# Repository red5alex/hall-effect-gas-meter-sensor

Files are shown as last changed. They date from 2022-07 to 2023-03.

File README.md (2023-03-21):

# HallEffectGasMeter

**Reading a Gas Meter with Magnetic Encoder using a Hall Effect sensor and an ESP32**

Building a device for reading the pulse count of a gas meter using a hall effect sensor, and sending the counter value to an MQTT broker for further processing. I tried it over one winter and it worked almost perfekt (lost about 1% of the pulses). **It was, however, necessary to solder the wires instead of using the DuPont connectors shown in the pictures below.**

**Note**: Besides using the magnetic counter, the Actaris G4 RF1 also features a reflective encoder on the .001-wheel, allowing for optic reading with 10-fold resolution than the magnetic encoder on the .01 wheel. I realized this only when I already had completed the build, and would have probably gone that way if I would have been aware of it earlier. I recommend to check out Geert Meersman's project https://github.com/geertmeersman/energie-meter which uses this approach.

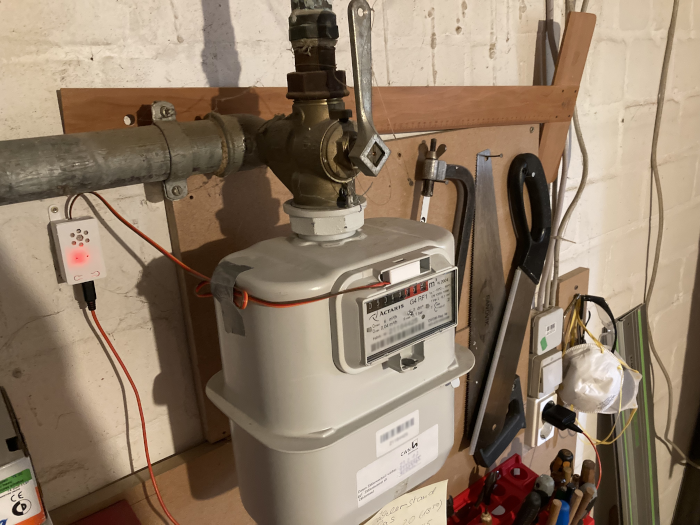
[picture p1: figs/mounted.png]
picture of the sensor mounted to the gasmeter


## Hardware used

- 1 x hall effect sensor 4913B TLE4913 (49E)
- 1 x ESP32 or ESP8266 (or any microcontroller board with WiFi and ADC)
- 3 x Dupont wires (female-female)
- some kind of server to send MQTT messages to (e.g. node-red, home-assistant...)

This hall effect sensor is latching, meaning that it shifts between a HIGH and a LOW state with hysteresis.
The states do depend on the reference voltage of the ESP, so they are different if the board is powered using 3.3V input or 5V (USB).

Note: I tried a classic mechanical Reed sensor with this setup to no avail. Changing to a digital sensor with inbuilt hysteresis made the difference

## Checking the gasmeter

My gasmeter is an Actaris G4 RF1, however I am positive this setup can read-out any other meter with a magnetic pulse.

One of the rollers contains a magnet encoder. I was able to figure out which one it is by moving a strong magnet in the vicinity which caused the relevant one to wiggle a little bit. The sensor must be placed close to this roller.

## 3D printed sensor holder

To hold the sensor in place, I have created a printable piece of plastic that press-fits into the slot above the holder and holds the sensor and cable firmly in place. Find the 3D print files here: https://www.printables.com/model/247665-hall-effekt-gas-meter-reader

The CAD model (made in OnShape) can be found [here]([https://www.google.com](https://cad.onshape.com/documents/e0d259fd877c1182a09bbc17/w/994389497a324f97073d213b/e/8d6a3ead179d19c52f29340c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)

If you do not have a 3D printer, play dough should do just fine :)

After printing, the sensor slides into the little notch. Now, attach the dupont cables to the sensor's terminals and press them into the little grove.
On the picture, I replaced the three original single dupont shells with a triple one, which makes handling a bit easier. If you go with the original terminals, you can secure them by wrapping sticky tape around it.
**Note from future author**: I only got a stable connection when actually soldering the wires, the Dupont connectors created false readings from time to time.

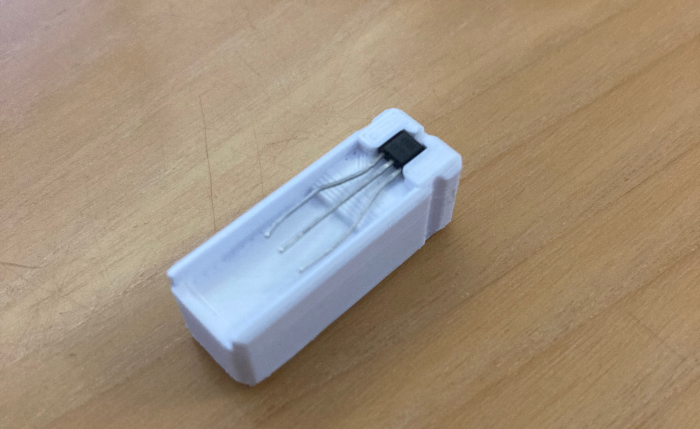
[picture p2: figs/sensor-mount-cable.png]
attach the cables and push in grove


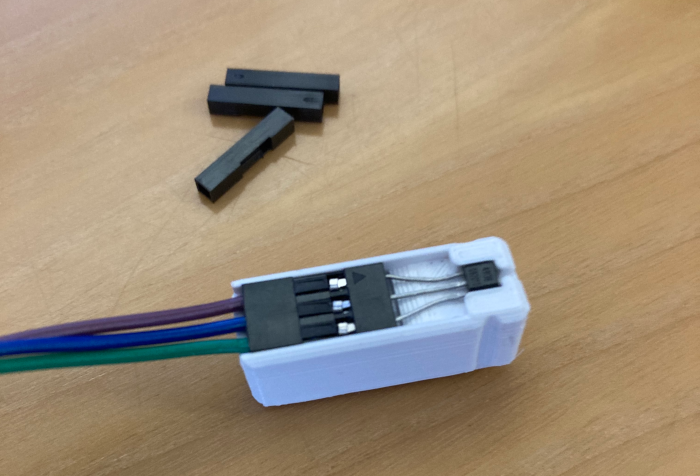
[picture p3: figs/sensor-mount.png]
slide the sensor in the notch


The whole assembly now slides into the slot above the digit rollers of the meter. There is a slit on the side of the mount to indicate the sensors position (highlighted with a pen on the picture), which should be placed directly above the roller containing the magnet.

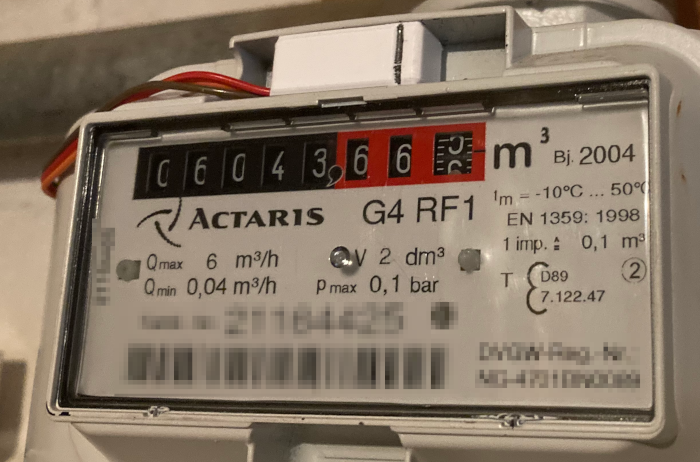
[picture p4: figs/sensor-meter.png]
slide the assembly into the slot above the meter digit rollers


## Wiring

Connect the opposite end of the Dupont cables with the corresponding terminals of the Microcontroller>

- GND to GND
- 3V3 to 3V3
- The signal terminal to GPIO34

You can choose another GPIO with ADC capability (see pinout of you DevBoard). Note: On ESP32, you cannot use the pins connected to ADC2 when using WiFi.

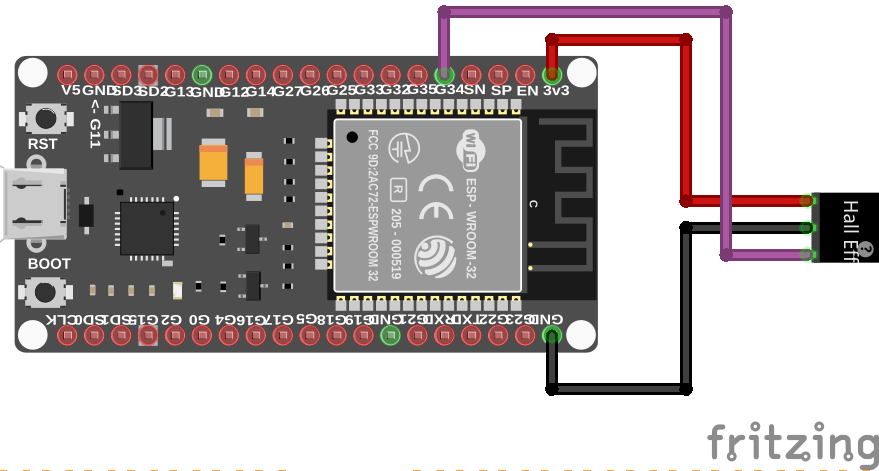
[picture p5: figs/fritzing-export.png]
wiring schematics


## The Ardunio Sketch

The Arduino sketch in the repository contains several configuration files:

- `are_wifi_config.h` sets the hostname and LED port
- `are_mqtt_config.h` configures the MQTT broker, topic etc. If using a public broker (e.g. HiveMQ), make sure to change the default topic.
- `credentials-template.h` must be renamed to `credentials.h`. Add you WiFi name and password here)
- The pinout for the LED and Sensor input can be changed in the `arduino-sketch.ino` directly.

Compile and upload, and check the Serial monitor.
At startup, the LED (if present) will flash until network connectivity is present.

After that, the status LED will be on if the sensor is connected but not detecting the presence of the magnet. Check the connection if it does not come up.

Place a magnet close to the sensor and check if it will turn off. If not, you may need to adjust the threshold voltage in the code (it differs e.g. if powering the ESP32 board via a 5V supply (USB) or a 3.3V supply).

If your board has no in-built or external LED, use the Serial Monitor instead.

## 3D printed case for MicroController

DuPont wires do not attach very reliantly on the ESP32 connectors, so it is advisable to encapsulate the microcontroller to make sure they do not fall off when moving the cables.

I used the [ESP32 Open MQTT gateway box](https://www.thingiverse.com/thing:5345637) by [Simedru Florin](https://https://www.thingiverse.com/simedruflorin) as an enclosure for my ESP32 DevKit (Checkout his designs if using other boards, e.g. ESP8266).

The Dupont cables can be routed through its openings and secured with hotglue. Below a picture of the final assembly:

picture of the sensor mounted to the gasmeter

## Example Application with Node-RED

The repository contains a minimal appliacation example, where the ESP32 sends the current count via an MQTT broker to node-red.

example nodes in node-red GUI

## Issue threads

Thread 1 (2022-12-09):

Update about the project

KevinWillemarck, 2022-12-09:
Hi, just saw this project because I am looking to do the same with my installation. I was just wondering since it is now winter if your setup is working?

jksukino, 2023-02-16:
I'm interested in this project too

geertmeersman, 2023-02-16:
Hi, I tried it but it gave me from time  to time inaccurate readings.
Have changed it and documented it here: https://github.com/geertmeersman/energie-meter

red5alex, 2023-03-21:
Hi All,
Sorry for the late reply. I have finally found the time to test the setup and it worked out that except for a few glitches it works. However I believe @geertmeersman 's approach is superior, as the 0.1 m³ resolution of the magnetic pulse is somewhat low. I have therefore added a recommendation for your approach in the description. When I noticed the reflective surface myself I was already finished with the setup and regretted not going that way already ;). If for any reason I have to rework this setup I may try combining both sensors as it would provide some error check.

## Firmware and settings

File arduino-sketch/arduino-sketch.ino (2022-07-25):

/*
  Sketch for reading a Hall Latch Sensor

  If this does not perform, these are ideas to improve:
  - Add voltage divider to board for larger input range of sensor
  - add hysteresis in this script as additional noise filter
  - only trigger if there was no state change for n seconds.

*/

#include <Arduino.h>
#include <PubSubClient.h>

#include "credentials.h"

// load wifi library and - settings
#include "are_wifi_config.h"
#include "are_wifi.h"
#include "are_mqtt_config.h"
#include "are_mqtt.h"

// pin definition
const int analogInPin = 34;  // Connect to Signal pin of 4913B TLE4913 Hall Effect Sensor
const int LedPin = GPIO_LED;  // Analog input pin that the potentiometer is attached to
const int threshold = 4094;  // this is for 5V Power Supply

// variables
long lastMsg = 0; // time counter for MQTT intervalls
int state = 1;
int counter = 0;
int sensorValue = 0;
int sensorValue_last = 0;
bool sensor_high = false;
bool sensor_rising = false;
bool notify_serial = false;
bool notify_mqtt = false;


//MQTT settings
WiFiClient espClient;
PubSubClient mqttclient(espClient);

/* MQTT callback
   This code sections reacts to incoming MQTT messages.
*/

void callback(char* topic, byte* message, unsigned int length) {
  Serial.print("mqqt message arrived on topic: ");
  Serial.println(topic);

  // cast payload to string object
  String messageTemp;
  Serial.print("Message: ");
  for (int i = 0; i < length; i++) {
    Serial.print((char)message[i]);
    messageTemp += (char)message[i];
  }
  Serial.println();


  /*
    // Changes the output state according to the message and publish a confirmation
    if (String(topic) == TOPIC_LED_CMD) {
    if (messageTemp == "on") {
      Serial.println("LED on");
      digitalWrite(GPIO_LED, HIGH);
      mqttclient.publish(TOPIC_LED_STATUS, "on");
    }
    else if (messageTemp == "off") {
      Serial.println("LED off");
      digitalWrite(GPIO_LED, LOW);
      mqttclient.publish(TOPIC_LED_STATUS, "off");
    }
  */
  // Add more commands here ...


}


void setup() {
  Serial.begin(9600);
  pinMode(LedPin, OUTPUT);

  // initialize device
  //pinMode(GPIO_LED, OUTPUT);

  // connect to Wifi
  connect_to_wifi(WIFI_SSID, WIFI_PASSWORD, WIFI_HOSTNAME);

  // Connect to MQTT Server
  mqttclient.setServer(MQTT_SERVER, MQTT_PORT);
  mqttclient.setCallback(callback);

  Serial.print("MQTT topic for publishing: ");
  Serial.println(TOPIC_SENSOR_HALL);

}

void loop() {


  // let mqtt work
  mqttclient.loop();
  
  notify_serial = false;
  notify_mqtt = false;

  // read analog value:
  sensorValue = analogRead(analogInPin);
  //Serial.print(sensorValue);
  //Serial.println("\n");

  if (sensorValue > threshold)
    sensor_high = true;
  else
    sensor_high = false;

  if (sensorValue > sensorValue_last)
    sensor_rising = true;
  else
    sensor_rising = false;


  // register state 1 (no magnetic counter)
  if ((sensorValue > threshold) && (state == 0))
  { state = 1;
    counter++;
    digitalWrite(LedPin, HIGH);
    notify_serial = true;
    notify_mqtt = true;
  }

  // register state 0 (magnetic counter detected)
  else if ((sensorValue < threshold) && (state == 1))
  { state = 0;
    digitalWrite(LedPin, LOW);
    notify_serial = true;
  }

  if (notify_serial)
  {

    // print the results to the Serial Monitor:
    Serial.print(sensor_high);
    Serial.print("\t");
    Serial.print(sensor_rising);
    Serial.print("\t");
    Serial.print(state);
    Serial.print("\t");
    Serial.print(counter);
    Serial.print("\t");
    Serial.println(sensorValue);
  }

  // check of MQTT message must be send due set message intervall
  long now = millis();
  if (now - lastMsg > MQTT_UPDATE_INTERVALL) {
    lastMsg = now;
    notify_mqtt = true;

  }

  if (notify_mqtt)
  {

    // ensure connection to mqtt broker
    mqtt_check_connection(&mqttclient);

    // Convert sensor reading from float to a char array
    char tempString[8];  // increase array length if having runtime errors
    dtostrf(counter, 1, 0, tempString);
    Serial.print("mqtt ");
    Serial.print(TOPIC_SENSOR_HALL);
    Serial.print(": ");
    Serial.print(tempString);
    Serial.println("\n");
    mqttclient.publish(TOPIC_SENSOR_HALL, tempString);
  }
 
  // delay to let the sensor settle on new value
  delay(5);
}

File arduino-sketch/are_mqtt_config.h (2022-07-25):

/*
 * Server settings
 * Below settings uses the public MQTT broker of HiveMQ.
 * Note: All messages are public!
 */


#define MQTT_SERVER "192.168.188.2"
#define MQTT_PORT 1883
//#define MQTT_USER NULL --> Create this in credentials.h
//#define MQTT_PASSWORD NULL --> Create this in credentials.h

#define MQTT_LASTWILL_TOPIC "red5alex/gasmeter/lastwill"
#define MQTT_LASTWILL_MESSAGE "connection lost"
#define MQTT_LASTWILL_QOS 0
#define MQTT_LASTWILL_RETAIN false

/*
 * MQTT Actions
 * MQTT messages causing an action, e.g. switching a relais, are configured here.
 * Note that the main code must still be implemented in the main script.
 * Actions are received on one topic, and a confirmation is send on a different topic.
 * Here, all actions topics are in the same branch to ease subscrition.
 */

#define MQTT_SUBSCRIBE_TOPIC "red5alex/gasmeter/cmd/#"  // all messages matching this topic pattern will be evaluated by the mqtt_callback function.
#define TOPIC_LED_CMD  "red5alex/gasmeter/cmd/led"  // send "on" or "off" to switch inbuil LED
#define TOPIC_LED_STATUS  "red5alex/gasmeter/status/led"  // command will be confirmed on this channel

/* 
 *  MQTT Sensor updates
 *  Sensors readings are send at an intervall, given below as milliseconds.
 */

#define MQTT_UPDATE_INTERVALL 300000  // milliseconds after which new sensor values are send
#define TOPIC_SENSOR_HALL  "red5alex/gasmeter/sensor/counter"  // publish the current counter value

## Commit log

2022-07-21 added arduino sketch
2022-07-24 MQTT working, sensor is connected to GPIO34
2022-07-25 added fritzing wiring schematics
    [Hall_Effect_Sensor.fzz]
2022-07-25 added mounted.png
